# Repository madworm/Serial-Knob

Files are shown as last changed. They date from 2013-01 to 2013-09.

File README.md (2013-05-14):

Serial-Knob
===========

LAYOUT FILES: Rotary encoder + microcontroller. Sends commands via serial.

ATtiny25/45/85 + ALPS STEC12E08.

The microcontroller can evaluate direction of rotation, speed and acceleration + button status.
Depending on the requirements, this can be encoded in one single byte and sent to the target.

Step / direction decoding is also possible. By adding a multiplicator, this board could also
be used as a stepper-controller tester. Turn the knob, and the stepper should follow.

You will find code for this project in [this](https://github.com/madworm/ATtiny_projects/tree/master/85/Serial-Knob) repository.

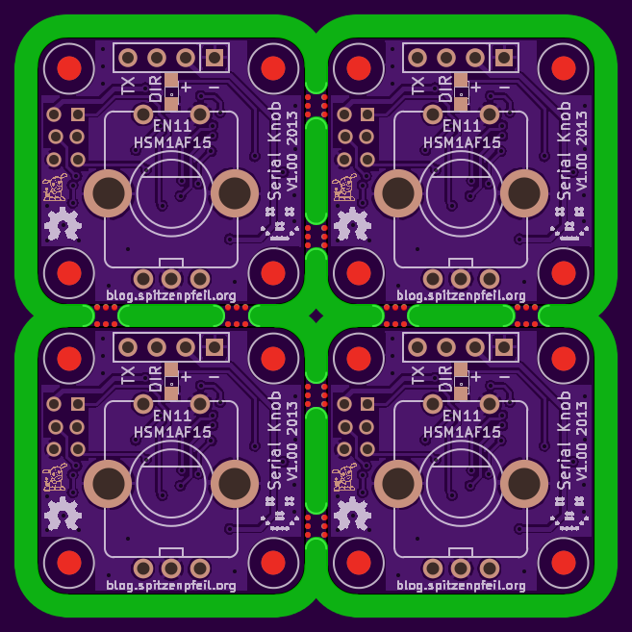
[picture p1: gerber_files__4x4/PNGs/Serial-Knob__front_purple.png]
Serial-Knob panel


---

Before having PC-boards made, please make sure you know about your manufacturer's peculiarities!
Especially drill-sizes and their tolerances may vary too much and give you trouble.

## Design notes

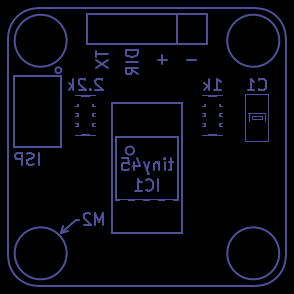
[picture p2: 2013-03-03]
gerber_files/PNGs/Serial-Knob-B_SilkS.gbo.png

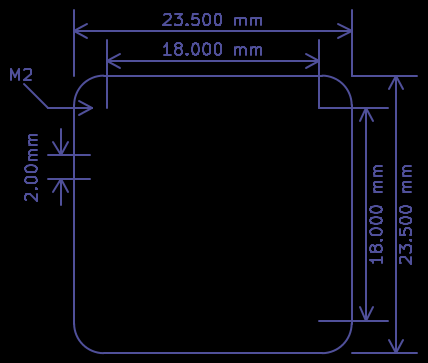
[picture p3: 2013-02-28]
gerber_files/PNGs/Serial-Knob-Cmts_User.gbr.png

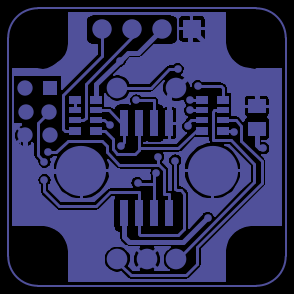
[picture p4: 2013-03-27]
gerber_files/PNGs/Serial-Knob-B_Cu.gbl.png

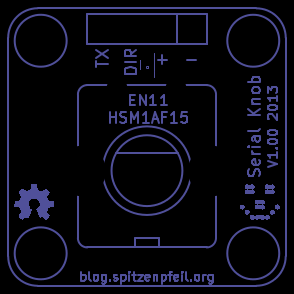
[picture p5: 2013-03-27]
gerber_files/PNGs/Serial-Knob-F_SilkS.gto.png

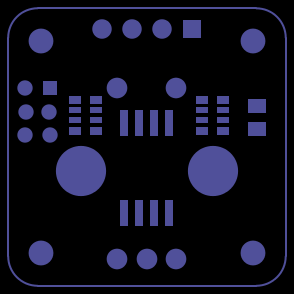
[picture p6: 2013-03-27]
gerber_files/PNGs/Serial-Knob-B_Mask.gbs.png

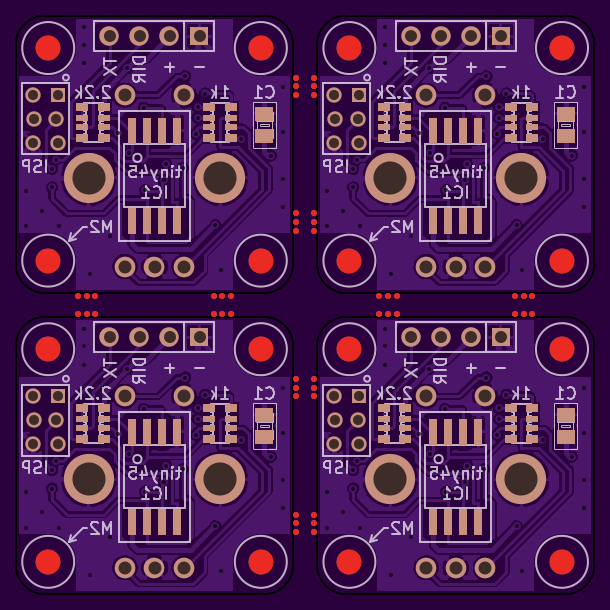
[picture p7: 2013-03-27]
gerber_files__4x4/PNGs/Serial-Knob__back_purple.png

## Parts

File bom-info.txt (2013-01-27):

Alternative parts:
------------------

ALPS STEC12E08 <--> EN12-HS22AF30 (Digikey: 987-1196-ND)

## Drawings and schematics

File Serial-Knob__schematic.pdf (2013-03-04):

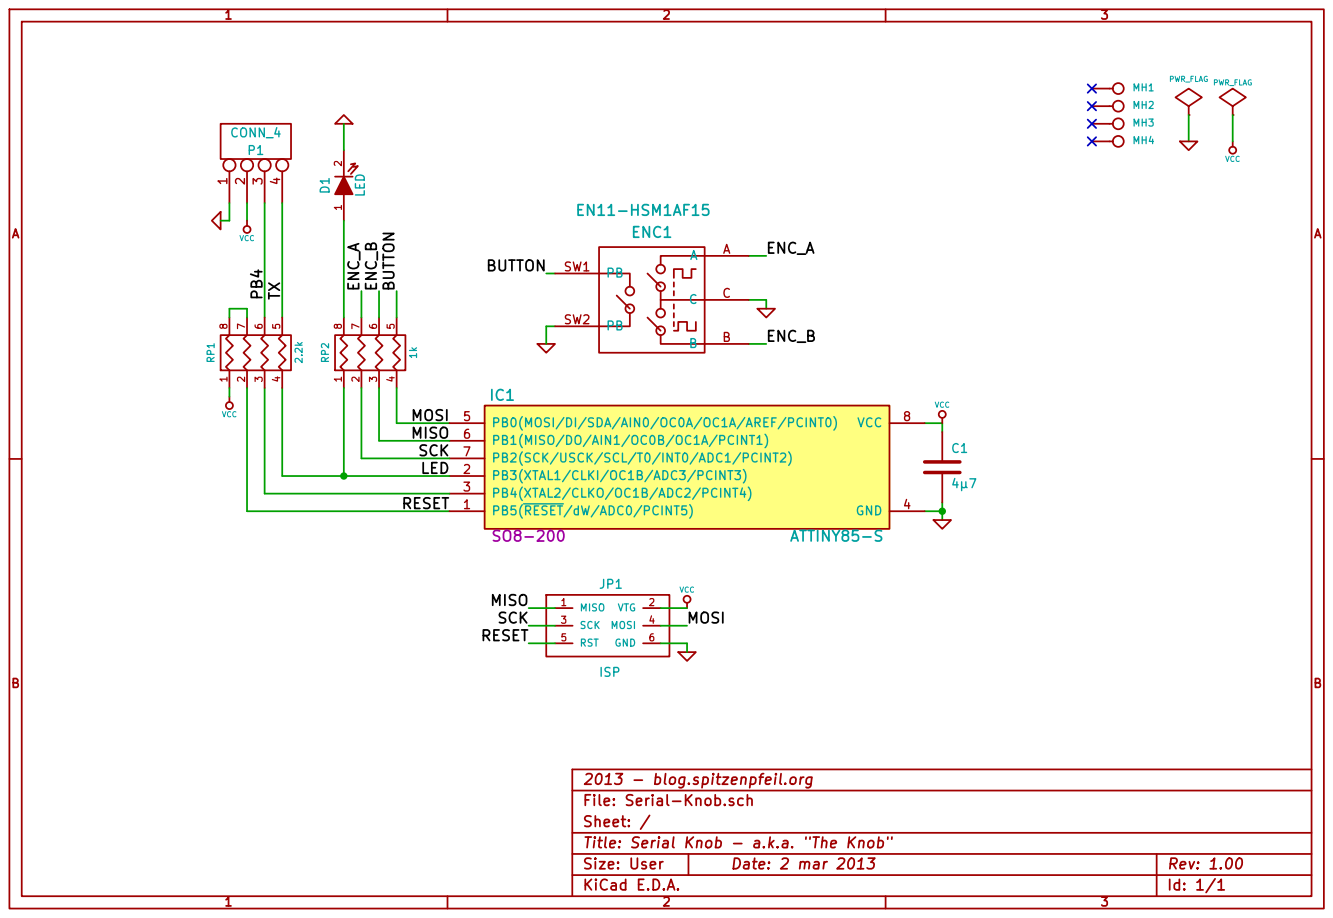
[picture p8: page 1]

File: Serial-Knob.sch
Sheet: /
Title: Serial Knob - a.k.a. "The Knob"

Size: User | Rev: 1.00

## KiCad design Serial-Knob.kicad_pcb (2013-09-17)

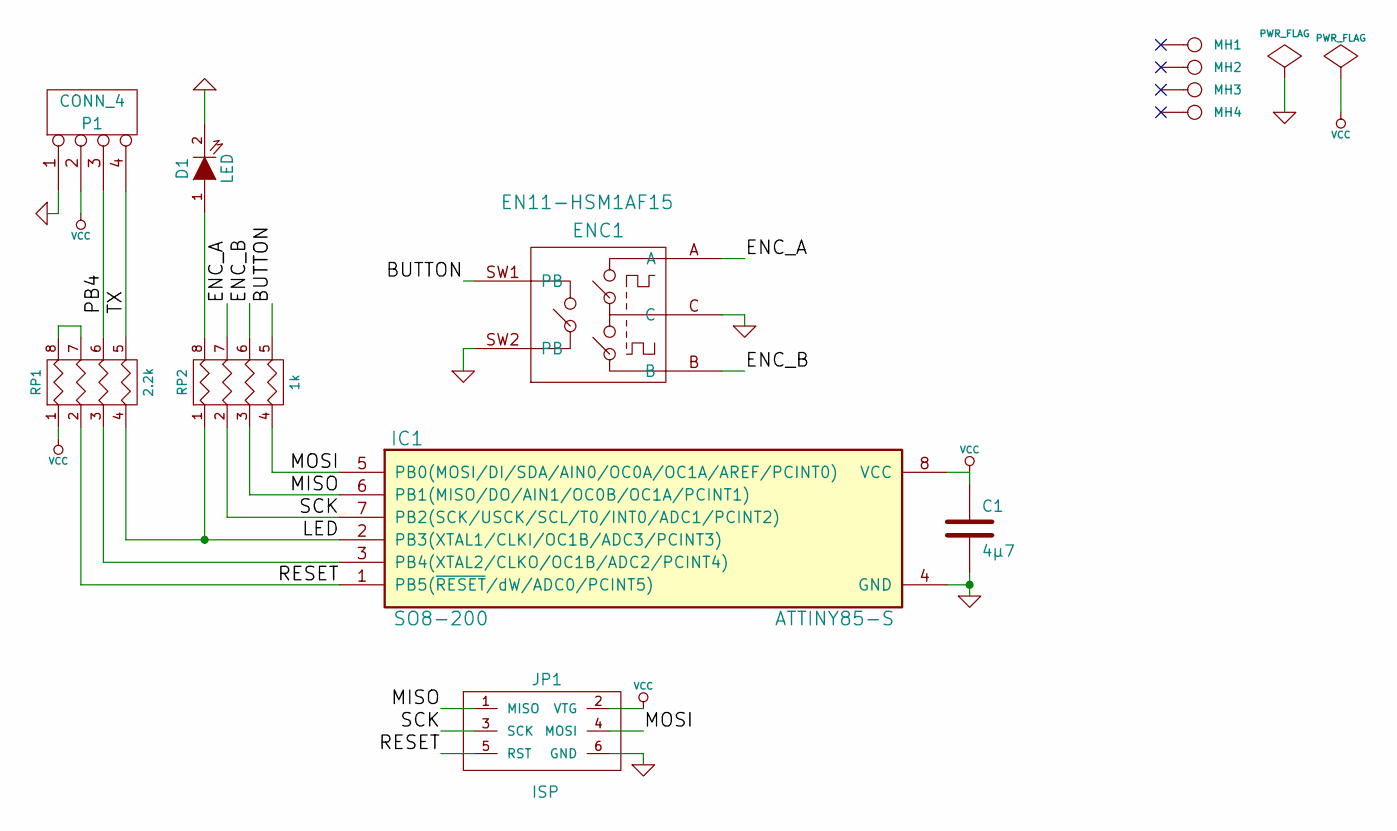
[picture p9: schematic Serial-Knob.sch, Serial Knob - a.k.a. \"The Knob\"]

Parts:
C1: 4µ7
D1: LED
ENC1: EN11-HSM1AF15
IC1: ATTINY85-S; SO8-200
JP1: ISP
MH1, MH2, MH3, MH4: CONN_1
P1: CONN_4
RP1: 2.2k
RP2: 1k

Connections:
/BUTTON: ENC1.SW1 (PB), RP2.5 (R4)
/ENC_A: ENC1.A, RP2.7 (R2)
/ENC_B: ENC1.B, RP2.6 (R3)
/LED: IC1.2 (PB3(XTAL1/CLKI/OC1B/ADC3/PCINT3)), RP1.4, RP2.1
/MISO: IC1.6 (PB1(MISO/DO/AIN1/OC0B/OC1A/PCINT1)), JP1.1 (MISO), RP2.3
/MOSI: IC1.5 (PB0(MOSI/DI/SDA/AIN0/OC0A/OC1A/AREF/PCI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), JP1.4 (MOSI), RP2.4
/PB4: P1.3, RP1.6 (R3)
/RESET: IC1.1 (PB5(~RESET~/dW/ADC0/PCINT5)), JP1.5 (RST), RP1.2
/SCK: IC1.7 (PB2(SCK/USCK/SCL/T0/INT0/ADC1/PCINT2)), JP1.3 (SCK), RP2.2
/TX: P1.4, RP1.5 (R4)
GND: C1.2, D1.2 (K), ENC1.C, ENC1.SW2 (PB), ENC1.body, IC1.4 (GND), JP1.6 (GND), P1.1
unnamed: IC1.3 (PB4(XTAL2/CLKO/OC1B/ADC2/PCINT4)), RP1.3
unnamed: RP1.7 (R2), RP1.8 (R1)
unnamed: D1.1 (A), RP2.8 (R1)
VCC: C1.1, IC1.8 (VCC), JP1.2 (VTG), P1.2, RP1.1

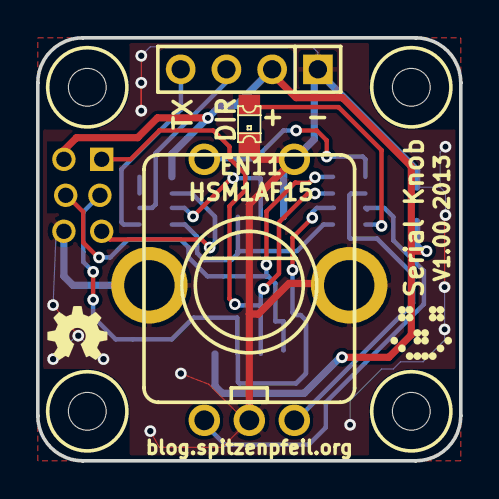
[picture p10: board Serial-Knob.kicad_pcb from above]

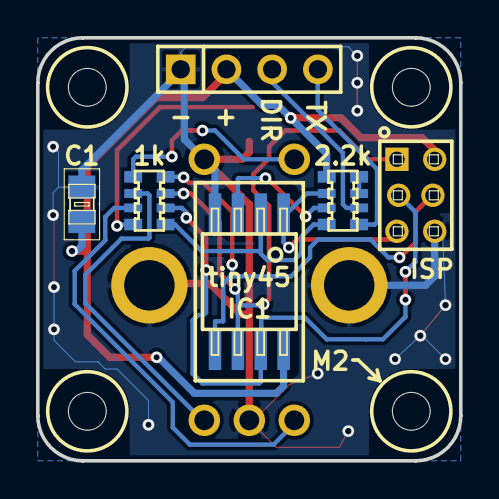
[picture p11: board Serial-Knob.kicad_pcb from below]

Board: 2 copper layers, 23.5 x 23.5 mm, 15 parts (5 on the bottom side), 15 nets.

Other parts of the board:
G1: OSHW_LOGO
G2: LED_SMILE
G3: TINDIE_DOG

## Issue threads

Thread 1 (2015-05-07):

myparts.lib missing

LFSaw, 2015-05-07:
Hello,

I tried to extract the footprint for the ALPS encoder from this project, however, the myParts.lib is missing and the project does not open on my machine... (you set an absolute path to the library...)

madworm, 2015-05-07:
The schematic symbols area cached in "Serial-Knob-cache.lib", so it should work.

If you're just after the footprint, try this: https://github.com/madworm/Rotary-Encoders.pretty

Closed 2015-05-18.

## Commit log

2013-01-22 Had to modify the encoder footprint (no more slot holes).
    [Serial-Knob-B_Mask.gbs, Serial-Knob-B_SilkS.gbo, Serial-Knob-Back.gbl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]
2013-01-22 Rounded board edges are much nicer.
    [Serial-Knob-B_Mask.gbs, Serial-Knob-B_SilkS.gbo, Serial-Knob-Back.gbl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]
2013-01-22 Added website link to F_SilkS.
    [Serial-Knob.brd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]
2013-01-22 Added a 6-pin ISP header - 2mm raster ;-(
    [Serial-Knob-B_Mask.gbs, Serial-Knob-B_SilkS.gbo, Serial-Knob-Back.gbl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]
2013-01-27 Removed obsolete text on B_SilkS.
    [Serial-Knob.brd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]
2013-01-27 Switched to REV. 202 of atmel.lib
    [Serial-Knob.brd, Serial-Knob.sch]
2013-01-27 0603 LED --> 0805 LED (as intended). Board 0.5mm wider + taller now.
    [Serial-Knob-B_Mask.gbs, Serial-Knob-B_SilkS.gbo, Serial-Knob-Back.gbl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]
2013-02-05 Made pin #1 of the ISP header rectangular.
    [Serial-Knob.brd]
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2013-02-11 Increased annular ring size for the SIL-4 header.
    [Serial-Knob-B_Mask.gbs, Serial-Knob-B_SilkS.gbo, Serial-Knob-Back.gbl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]
2013-02-13 Silkscreen updates + added version number.
    [Serial-Knob.brd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]
2013-02-13 Flipped ISP header to backside + tweaks.
    [Serial-Knob-B_Mask.gbs, Serial-Knob-B_SilkS.gbo, Serial-Knob-Back.gbl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]
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2013-02-15 Added some artwork to the front side ;-)
    [Serial-Knob.brd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]
2013-02-18 Added some dimensions to the comment layer.
    [Serial-Knob.brd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]
2013-02-23 Some behind the scenes stuff. Layout unchanged.
    [Serial-Knob.brd, Serial-Knob.sch]
2013-02-26 Shifted ISP header pads. Attempt to keep the header from falling out.
    [Serial-Knob-B_Mask.gbs, Serial-Knob-B_SilkS.gbo, Serial-Knob-Back.gbl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]
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2013-02-27 Changed the title of the worksheets (schematic + layout).
    [Serial-Knob.brd, Serial-Knob.sch]
2013-02-28 Added a couple of GND-plane stitches.
    [Serial-Knob-B_Mask.gbs, Serial-Knob-B_SilkS.gbo, Serial-Knob-Back.gbl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]
2013-02-28 Made the mounting clip of the encoder GND as well.
    [Serial-Knob-B_Mask.gbs, Serial-Knob-B_SilkS.gbo, Serial-Knob-Back.gbl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]
2013-02-28 Made the stitching-vias smaller.
    [Serial-Knob-B_Mask.gbs, Serial-Knob-B_SilkS.gbo, Serial-Knob-Back.gbl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]
2013-02-28 All R0603 --> R0805. Much faster to assemble.
    [Serial-Knob-B_Mask.gbs, Serial-Knob-B_SilkS.gbo, Serial-Knob-Back.gbl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]
2013-02-28 Shifted some tracks for better GND plane flow.
    [Serial-Knob.brd]
2013-03-01 Changed all vias to 0.65/0.35 + moved to 1206 resistor packs (4x).
    [Serial-Knob-B_Mask.gbs, Serial-Knob-B_SilkS.gbo, Serial-Knob-Back.gbl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]
2013-03-01 Tweaks + recreate gerbers.
    [Serial-Knob-B_Mask.gbs, Serial-Knob-B_SilkS.gbo, Serial-Knob-Back.gbl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]
2013-03-01 Eliminated reset pullup by using unused rpack pins + now one 2.2k rpack.
    [Serial-Knob-B_Mask.gbs, Serial-Knob-B_SilkS.gbo, Serial-Knob-Back.gbl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]
2013-03-01 Moved some vias + traces.
    Now there's enough room to move the mounting holes inwards a bit. That
    way the encoder footprint is easily switched from EN12 types to EN11.
    [Serial-Knob-B_Mask.gbs, Serial-Knob-B_SilkS.gbo, Serial-Knob-Back.gbl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]
2013-03-01 Found a via that interfered with silkscreen text.
    [Serial-Knob-B_Mask.gbs, Serial-Knob-B_SilkS.gbo, Serial-Knob-Back.gbl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]
2013-03-02 ENC footprint made to fit EN11-HSM1AF15. Need to do it properly later.
    [Serial-Knob-B_Mask.gbs, Serial-Knob-B_SilkS.gbo, Serial-Knob-Back.gbl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]
2013-03-02 Switched footprint to MADW__EN11-HSM1AF15. All proper now.
    [Serial-Knob-B_Mask.gbs, Serial-Knob-B_SilkS.gbo, Serial-Knob-Back.gbl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]
2013-03-02 Moved the LED a bit farther away from the encoder knob.
    [Serial-Knob-B_Mask.gbs, Serial-Knob-B_SilkS.gbo, Serial-Knob-Back.gbl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]
2013-03-03 Moved ISP header a bit away from board edge + shifted some vias.
    [Serial-Knob-B_Mask.gbs, Serial-Knob-B_SilkS.gbo, Serial-Knob-Back.gbl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]
2013-03-03 A shifty business with vias. 'Tindie' is now back on the .gts layer.
    [Serial-Knob-B_Mask.gbs, Serial-Knob-B_SilkS.gbo, Serial-Knob-Back.gbl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]
2013-03-04 Upped version number to 1.00
    [Serial-Knob-B_Mask.gbs, Serial-Knob-B_SilkS.gbo, Serial-Knob-Back.gbl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]
2013-03-05 Made a 4x4 'panel'.
    [Serial-Knob__4x4-B_Mask.gbs, Serial-Knob__4x4-B_SilkS.gbo, Serial-Knob__4x4-Back.gbl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]
2013-03-05 Added more drills to the break-away tabs.
    [Serial-Knob__4x4-B_Mask.gbs, Serial-Knob__4x4-B_SilkS.gbo, Serial-Knob__4x4-Back.gbl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]
2013-03-05 Some routing arcs were a bit off.
    [Serial-Knob__4x4-B_Mask.gbs, Serial-Knob__4x4-B_SilkS.gbo, Serial-Knob__4x4-Back.gbl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]
2013-03-06 Changed the break-away tabs for the 4x4 panel.
    [Serial-Knob__4x4-B_Mask.gbs, Serial-Knob__4x4-B_SilkS.gbo, Serial-Knob__4x4-Back.gbl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]
2013-03-08 Forgot board ID + date on 4x4 panel.
    [Serial-Knob__4x4-B_Mask.gbs, Serial-Knob__4x4-B_SilkS.gbo, Serial-Knob__4x4-Back.gbl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]
2013-03-20 Replaced all the NPTH holes with "mouse-byte" footprints.
    [Serial-Knob__4x4-B_Cu.gbl, Serial-Knob__4x4-B_Mask.gbs, Serial-Knob__4x4-B_SilkS.gbo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]
2013-03-21 Fixed a typo.
    [Serial-Knob__4x4.kicad_pcb]
2013-03-23 Updated the 4x4 panel to newer mouse-bite footprint.
    [Serial-Knob__4x4.kicad_pcb]
2013-03-23 Recreated the 4x4-panel gerber files.
    [Serial-Knob__4x4-F_SilkS.gto]
2013-03-27 Renamed a few files to fit new KiCad layer naming.
    [Serial-Knob-B_Cu.gbl, Serial-Knob-F_Cu.gtl]
2013-03-27 Recreated some gerber files.
    [Serial-Knob-B_Cu.gbl, Serial-Knob-B_Mask.gbs, Serial-Knob-B_SilkS.gbo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]
2013-03-27 Updated the 4x4 panel to NPTH mounting holes as well.
    [Serial-Knob__4x4.kicad_pcb]
2013-03-27 Recreated some gerber files for the 4x4 panel.
    [Serial-Knob__4x4-B_Cu.gbl, Serial-Knob__4x4-B_Mask.gbs, Serial-Knob__4x4-B_SilkS.gbo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]
2013-05-16 4x4 panel: for some reason the F.Paste / B.Paste layers were missing.
    [Serial-Knob__4x4.kicad_pcb]
2013-05-16 4x4 panel: updated the gerber files as well (missing paste layers).
    [Serial-Knob__4x4-B_Paste.gbp, Serial-Knob__4x4-F_Paste.gtp]
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2013-09-17 Fixed missing module definitions (pcbnew BZR 4319 was barfing).
    [Serial-Knob.kicad_pcb, Serial-Knob__4x4.kicad_pcb]
